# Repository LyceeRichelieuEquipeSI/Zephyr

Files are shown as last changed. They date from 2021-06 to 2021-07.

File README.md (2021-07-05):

# Zephyr
Projet de capteur de CO2 qui a été primé aux Olympiades de Sciences de l'Ingénieur 2021



Voici l'implantation des différents composants :

Implantation Arduino projet Zéphyr

Le capteur choisi au final est le CO2 Grove de chez GOtronic : https://www.gotronic.fr/art-capteur-de-co2-grove-101020067-23839.htm

Les pièces sont disponibles au format STL!

Il faut imprimer les 4 articulations.

Si vous voulez en savoir plus, voici la présentation faite lors de la finale des Olympiades : 
https://youtu.be/IQtPWZz7KpU

Celle-ci est aussi disponible en pdf dans les documents associés.

Voici également une vidéo du projet réel : 
https://www.youtube.com/watch?v=lbtuWfUY2Ug

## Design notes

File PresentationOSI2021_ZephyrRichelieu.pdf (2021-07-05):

# Projet Zéphyr

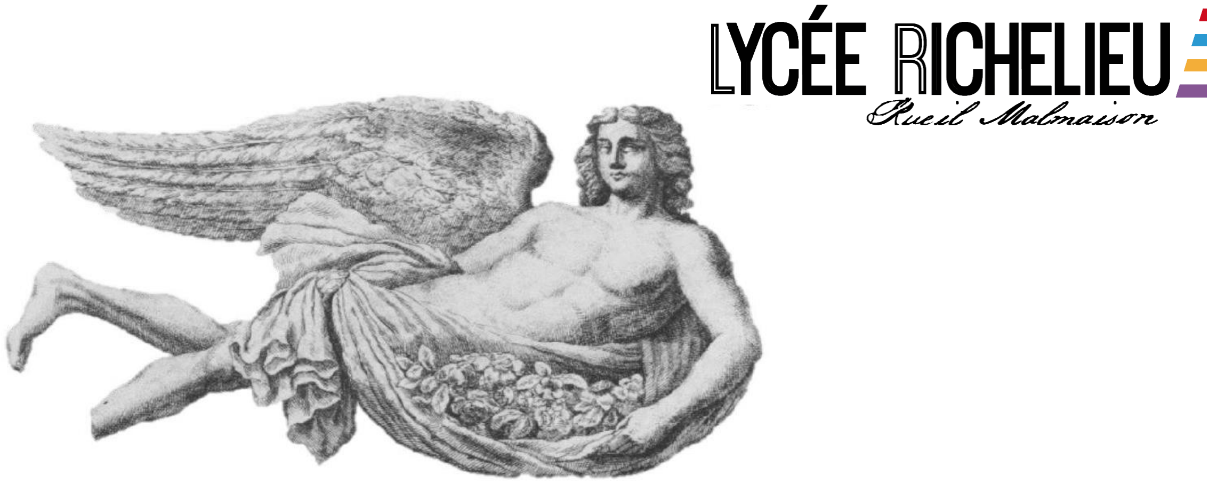
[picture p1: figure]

Le dieu grec Zéphyr,
personification du vent de l‘Ouest ou du Nord-Ouest.

Elèves de Première Spécialité Sciences de l’ingénieur

# Contexte sanitaire et social

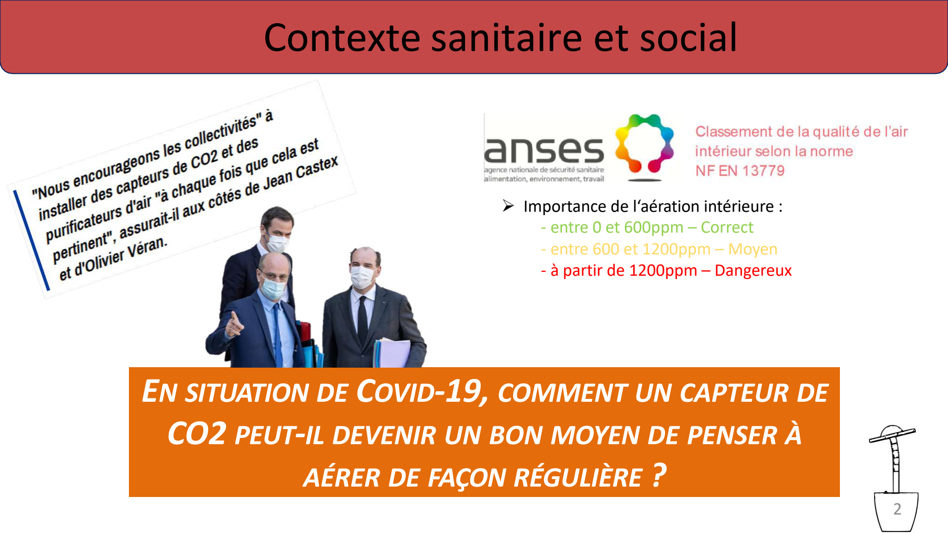
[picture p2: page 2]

## EN SITUATION DE COVID-19, COMMENT UN CAPTEUR DE CO2 PEUT-IL DEVENIR UN BON MOYEN DE PENSER À AÉRER DE FAÇON RÉGULIÈRE ?

Ø Importance de l‘aération intérieure :
- entre 0 et 600ppm – Correct
- entre 600 et 1200ppm – Moyen
- à partir de 1200ppm – Dangereux

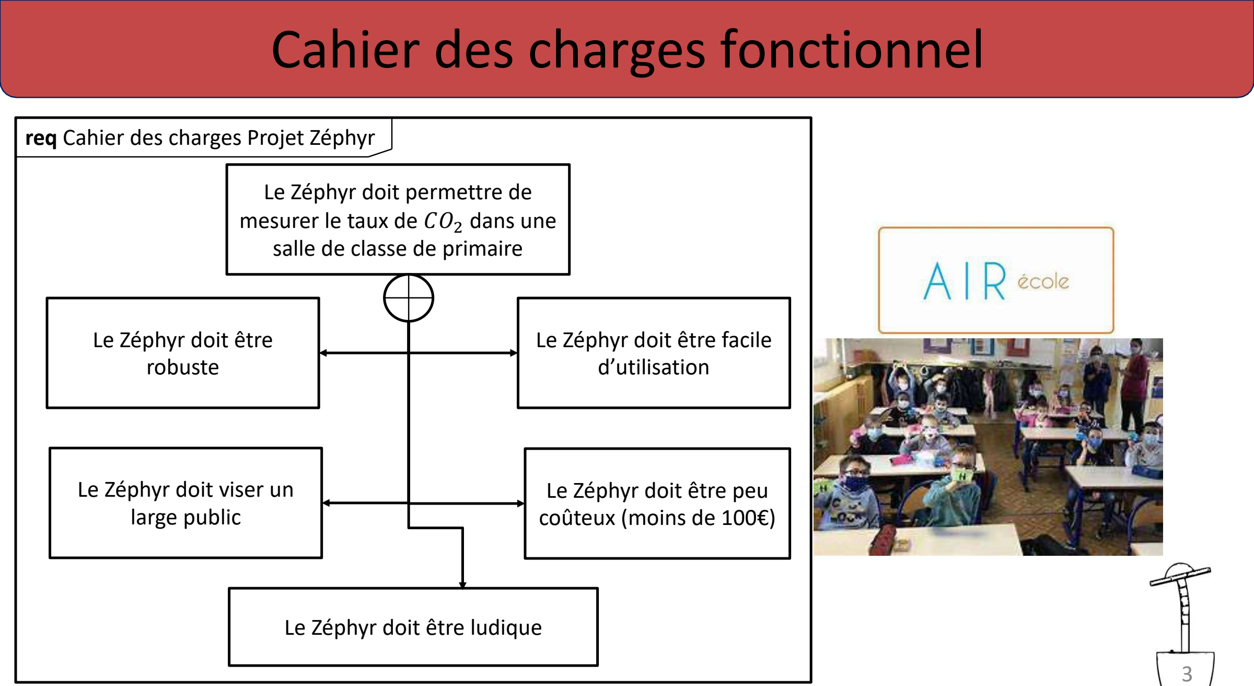
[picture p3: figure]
req Cahier des charges Projet Zéphyr; Cahier des charges fonctionnel; Le Zéphyr doit permettre de mesurer le taux de !"# dans une salle de classe de primaire; Le Zéphyr doit être facile d’utilisation; Le Zéphyr doit être peu coûteux (moins de 100€); Le Zéphyr doit être robuste; Le Zéphyr doit viser un large public; Le Zéphyr doit être ludique

# État de l’art

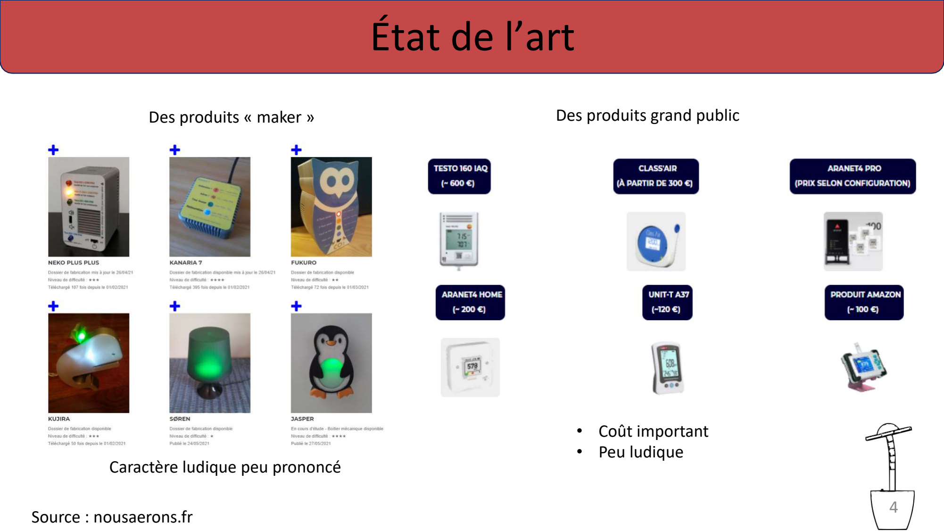
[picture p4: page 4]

Des produits grand public

- Coût important
- Peu ludique

Des produits « maker »

Caractère ludique peu prononcé

Source : nousaerons.fr | 4

# Notre projet Zéphyr

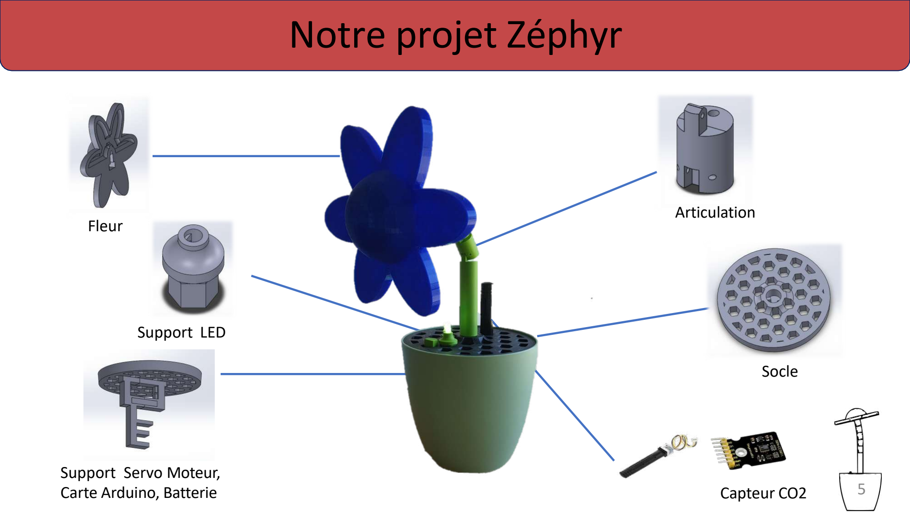
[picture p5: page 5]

Fleur

Articulation

Support LED

Capteur CO2

Support Servo Moteur,
Carte Arduino, Batterie

Socle

## Comment choisir un détecteur de CO2 ?

Un critère déterminant, la technologie du capteur.

- Capteur électrochimique trop délicat à calibrer.

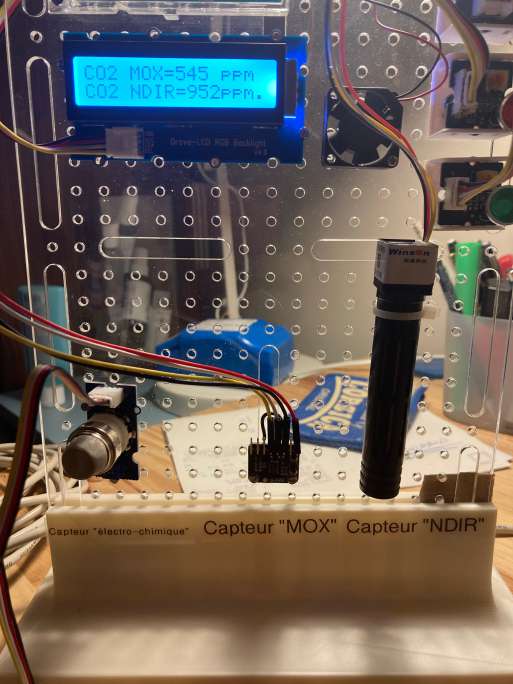
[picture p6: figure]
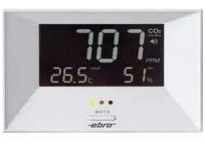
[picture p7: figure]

Banc d’essai

- Capteur NDIR certifié (a été comparé avec un capteur CO2 certifié étalonné)

Ø Les essais ont été réalisés avec deux capteurs : MOX et NDIR

# Fonction Acquérir

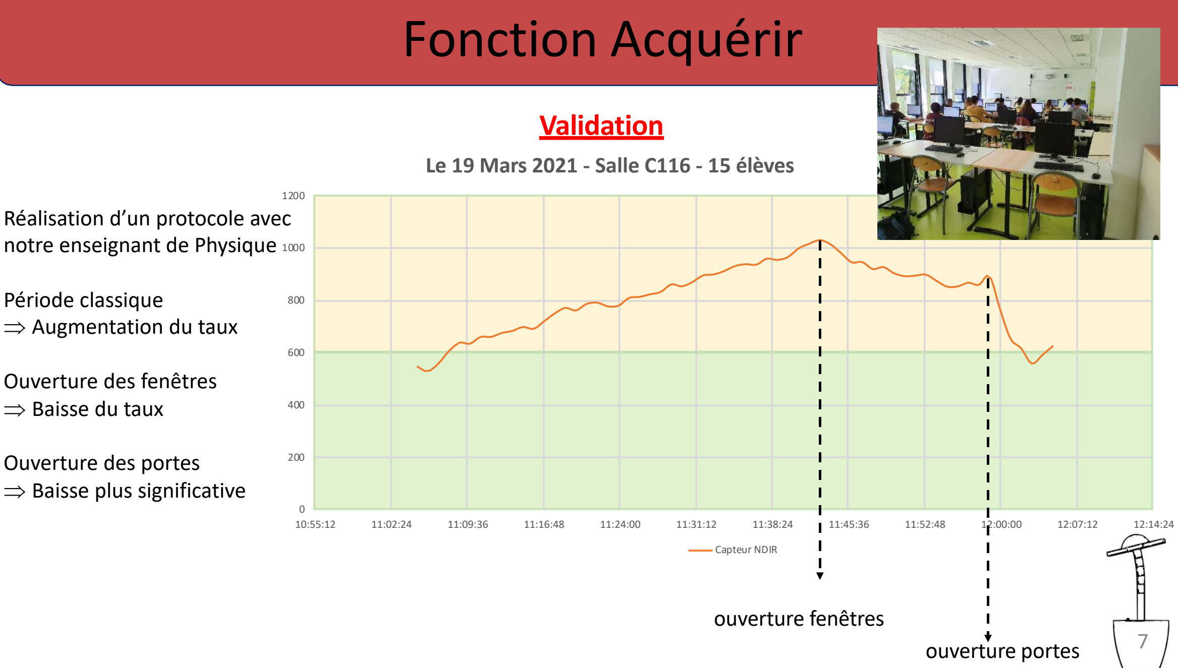
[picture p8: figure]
Fonction Acquérir; Validation; Capteur NDIR; ouverture fenêtres; ouverture portes; Réalisation d’un protocole avec notre enseignant de Physique; Période classique Þ Augmentation du taux; Ouverture des fenêtres Þ Baisse du taux; Ouverture des portes Þ Baisse plus significative

Le 19 Mars 2021 - Salle C116 - 15 élèves

# Fonction Acquérir

## Résultats des essais

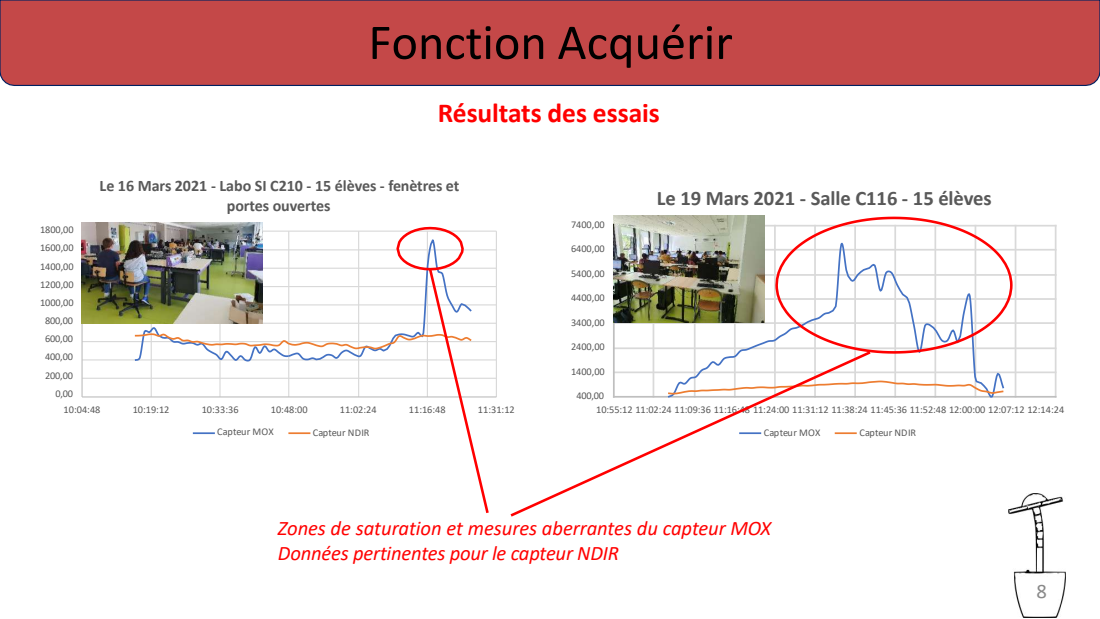
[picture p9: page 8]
portes ouvertes; Capteur MOX; Capteur NDIR

Le 16 Mars 2021 - Labo SI C210 - 15 élèves - fenètres et

Le 19 Mars 2021 - Salle C116 - 15 élèves

Zones de saturation et mesures aberrantes du capteur MOX
Données pertinentes pour le capteur NDIR

## Conclusion

## Les capteurs MOX sont à éviter !

Ø Un capteur MOX ne mesure pas directement le taux de CO2 (mais un « eCO2 », une estimation du CO2)

Ø Très sensible aux composés volatiles « parasites », comme les parfums

## Les capteurs NDIR (Non-Dispersive Infra Red) sont requis pour une

mesure exacte et fiable. De plus, ils sont très robustes.

# Fonction Acquérir

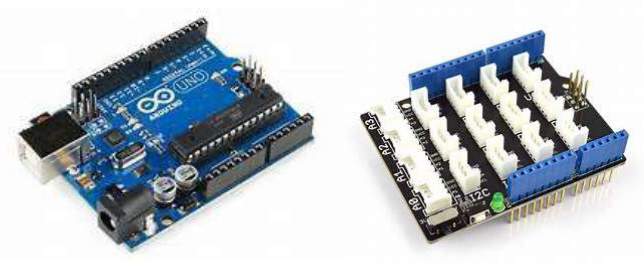
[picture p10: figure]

## - Carte Arduino UNO (microcontrôleur ATMega328 + Shield Grove)

## - Code Arduino, découpé en fonctions

# Fonction Traiter

## - Communication lumineuse

# Fonction Communiquer

## - Communication via l‘orientation

Vert – 0 à 600ppm – Correct

Jaune – 600 à 1200ppm – Moyen

Rouge – Plus de 1200ppm – Dangereux

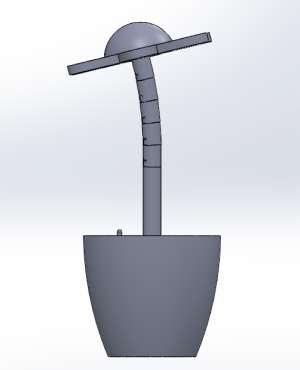
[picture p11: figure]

Plus de 1200ppm En dessous de 600 ppm

# Fonction Communiquer

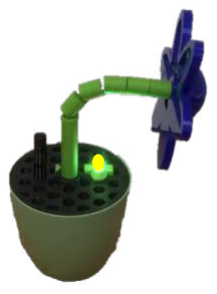
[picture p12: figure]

https://www.youtube.com/watch?v=lbtuWfUY2Ug | 12

## Taux de CO2 entre 0-600 ppm

## Taux de CO2 entre 600-1200 ppm

## Taux de CO2 de plus de 1200 ppm

## Parfait !

## Ouvrir une ou plusieurs fenêtres

## Créer un courant d‘air

## - Batterie LiPO 7.4 V – 1000 mAh - Disponible dans notre laboratoire - Modèle classique d’aéromodélisme

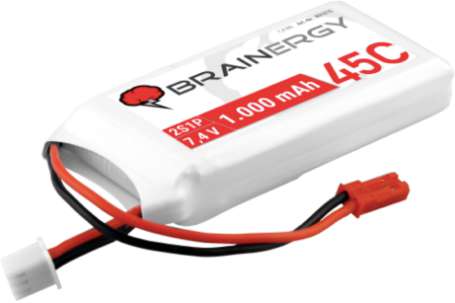
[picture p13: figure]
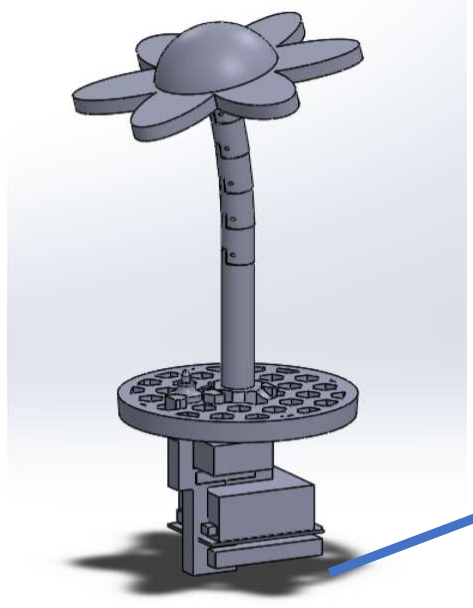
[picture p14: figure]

## Facile d‘accès

Est-ce que cette batterie tient une journée d’école ?

# Fonction Alimenter

# Fonction Alimenter

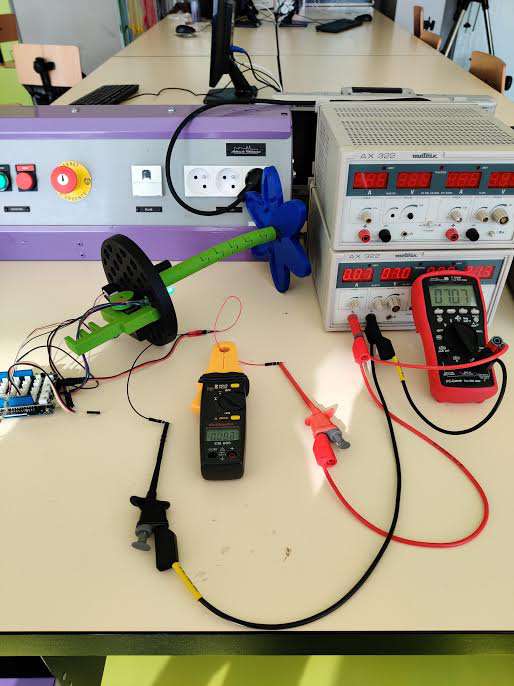
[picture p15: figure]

Mesures :

Ø Courant absorbé par la carte :

- moteur non alimenté : !" = 80 &'
- moteur alimenté : !( = 170 &'

Ø Tension mini de fonctionnement de la carte :

- +,-. = 5,2 2

### 2 hypothèses :

- Alimenté 2 fois en 1h selon le graphique pendant 2 secondes
- Le couple du moteur suffit pour le maintient de la fleur

Calculs :

Ø Courant moyen absorbé par la carte sur 1h :

- !"#$ = &
' ∑ !.*+
- !"#$ = &,- ∗/ ∗/ 0 1- ∗ 23--4/ ∗/ 23--
- !"#$ = 80,1 9:

Ø Autonomie:

* = ;
<=>?
t = 1000/80,1
t = 12,48 h = 12h 28 min

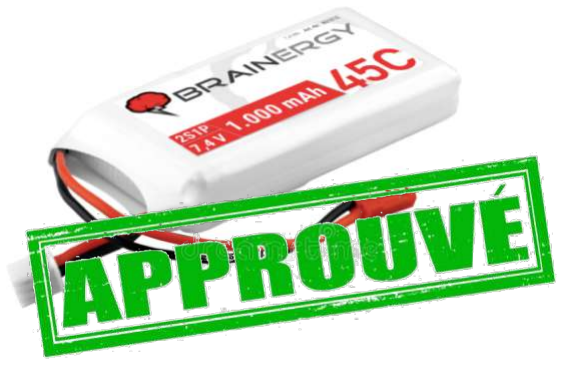
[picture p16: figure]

Beaucoup d’approximation, souhait de vérifier par modèle multiphysique

# Fonction Alimenter

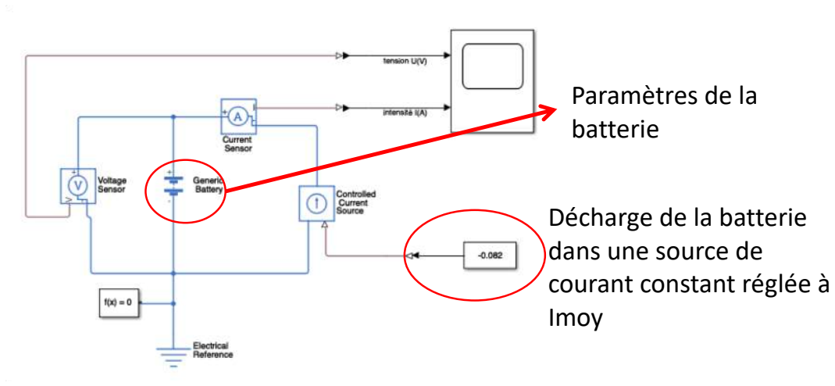
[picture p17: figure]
Décharge de la batterie dans une source de courant constant réglée à Imoy; Paramètres de la batterie
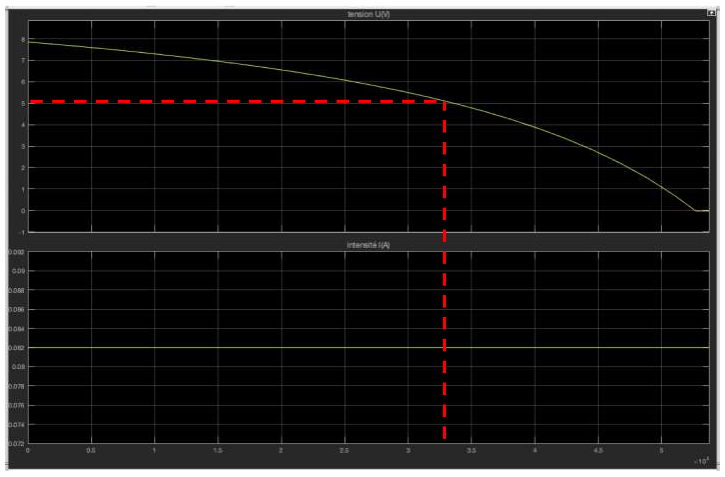
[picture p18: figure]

### Résultats de la simulation :

Pour !"#$ = 5.2 ) on a, t = 3.3 x 10⁴ s

Soit une autonomie de : 3.3 x 10⁴ /3600 = 9,17h = 9h 10 min

# Fonction Alimenter

## - Servomoteur Grove

# Fonction Convertir

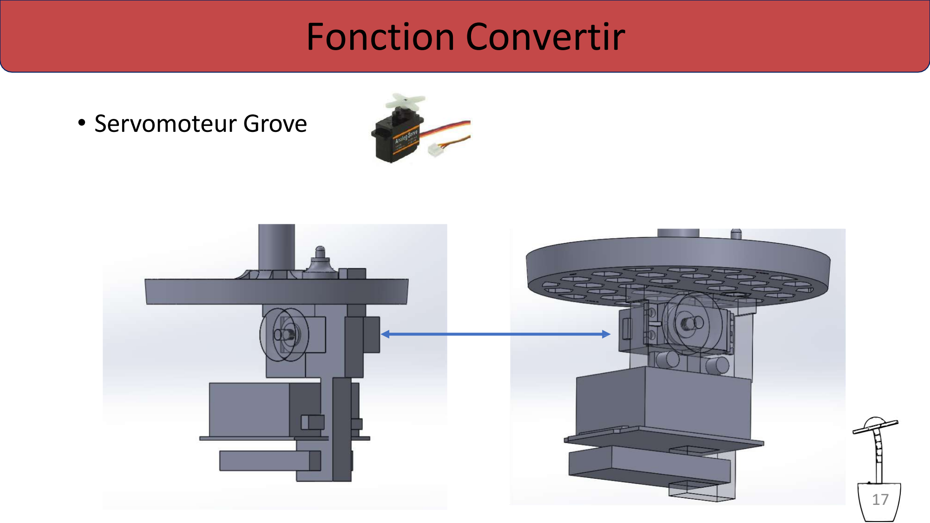
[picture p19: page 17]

## - Système poulie et câble :

# Fonction Transmettre

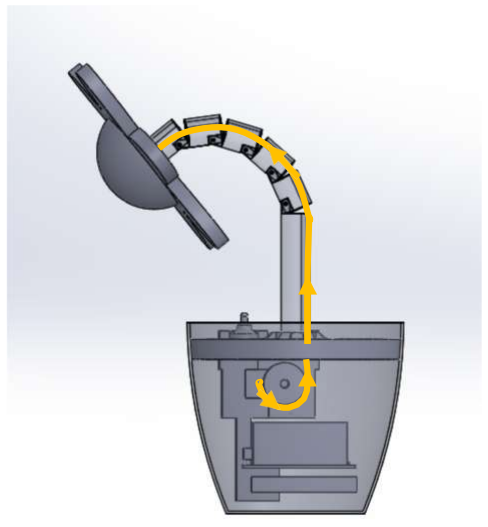
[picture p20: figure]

Lors de la rotation (sens1) du moteur, la poulie "déroule" du câble :
☞ la fleur s‘incline

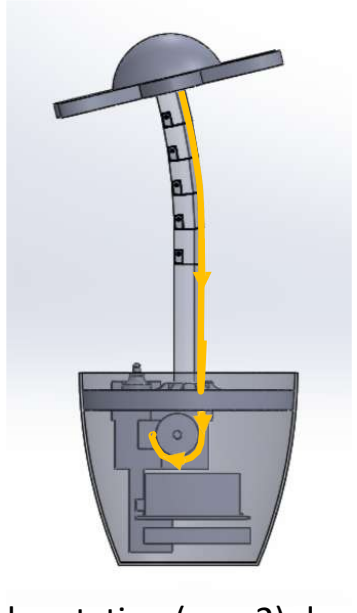
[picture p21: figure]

Lors de la rotation (sens2) du moteur, la poulie "enroule" du câble :
☞ la fleur se redresse

# Coût

Inducteurs de coût | Coût
Composants électroniques | 1+2+10+80 = 93 €
Matière première plastique | 14*0.6 = 8.4 €
Frais d’études
Amortir l’imprimante 3D (sur 1000 produits) | 600/1000 = 0.6 €
Amortir les licences Solidworks et Mathworks (sur 1000 produits) | (8000+2000)/1000 = 10 €
TOTAL | 112 €

# Bilan du projet

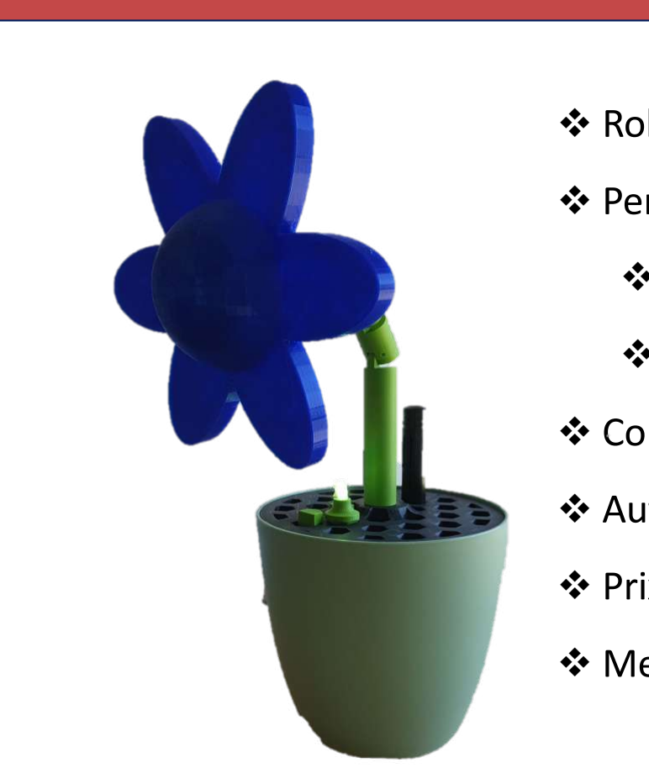
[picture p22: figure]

## v Robuste v Personnalisable : v Pot interchangeable v Nombre de niveaux intermédiaires choisissable v Communication par mouvement v Autonomie de plus de 9h v Prix d’environ 100 € v Mesure fiable du taux de CO2

# Bilan personnel

## v Mettre en place un protocole expérimental afin de valider les performances d‘un capteur et d’une batterie

## v Apprendre à structurer son code

## v Apprendre à trouver un compromis entre esthétique et solutions techniques

## v Apprendre à travailler en groupe

# Notre projet dans son contexte

## vUtilisation dans les locaux du lycée

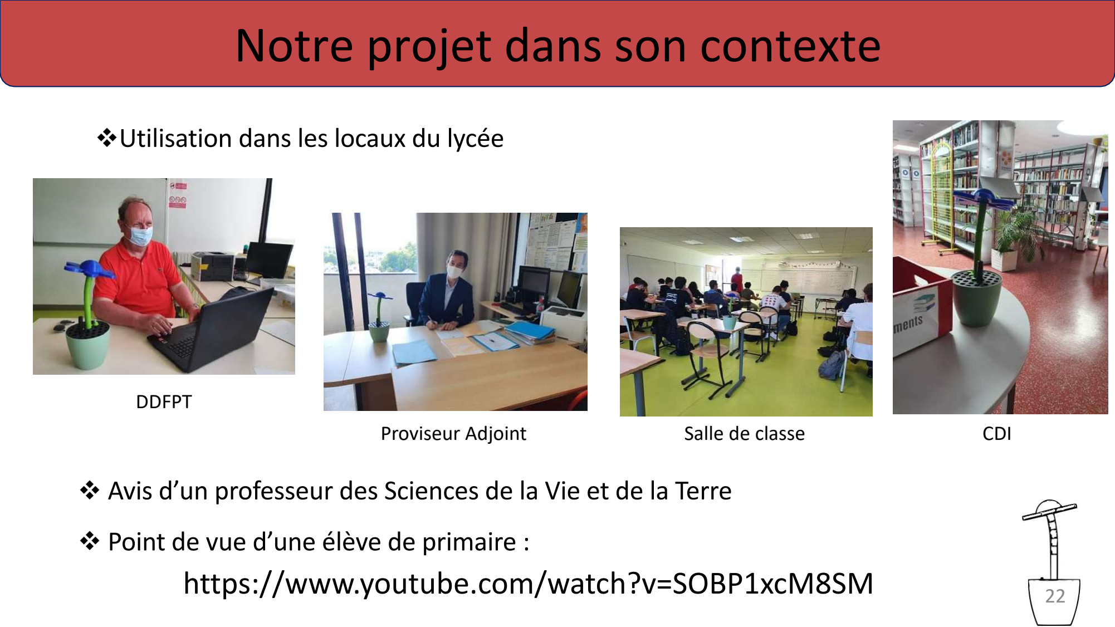
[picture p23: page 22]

## v Avis d’un professeur des Sciences de la Vie et de la Terre v Point de vue d’une élève de primaire :

## https://www.youtube.com/watch?v=SOBP1xcM8SM

DDFPT
Proviseur Adjoint | Salle de classe | CDI

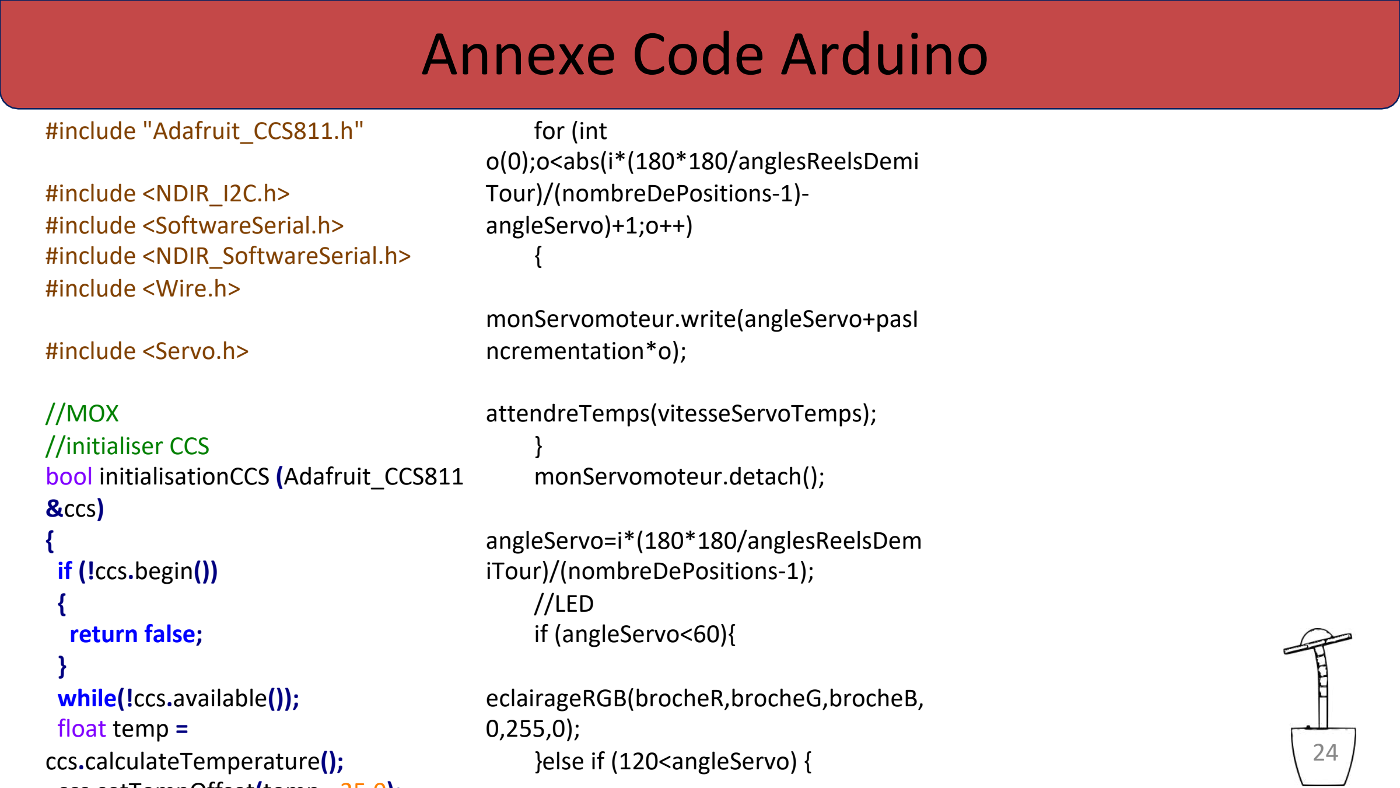
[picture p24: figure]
Annexe Code Arduino; #include "Adafruit_CCS811.h"; #include <NDIR_I2C.h> #include <SoftwareSerial.h> #include <NDIR_SoftwareSerial.h> #include <Wire.h>; #include <Servo.h>; //MOX //initialiser CCS bool initialisationCCS (Adafruit_CCS811 &ccs) {; if (!ccs.begin()) {; return false;; } while(!ccs.available()); float temp = ccs.calculateTemperature();; for (int o(0);o<abs(i*(180*180/anglesReelsDemi Tour)/(nombreDePositions-1)- angleServo)+1;o++) {; monServomoteur.write(angleServo+pasI ncrementation*o);; attendreTemps(vitesseServoTemps); } monServomoteur.detach();; angleServo=i*(180*180/anglesReelsDem iTour)/(nombreDePositions-1); //LED if (angleServo<60){; eclairageRGB(brocheR,brocheG,brocheB, 0,255,0);; }else if (120<angleServo) {

ccs.setTempOffset(temp - 25.0);

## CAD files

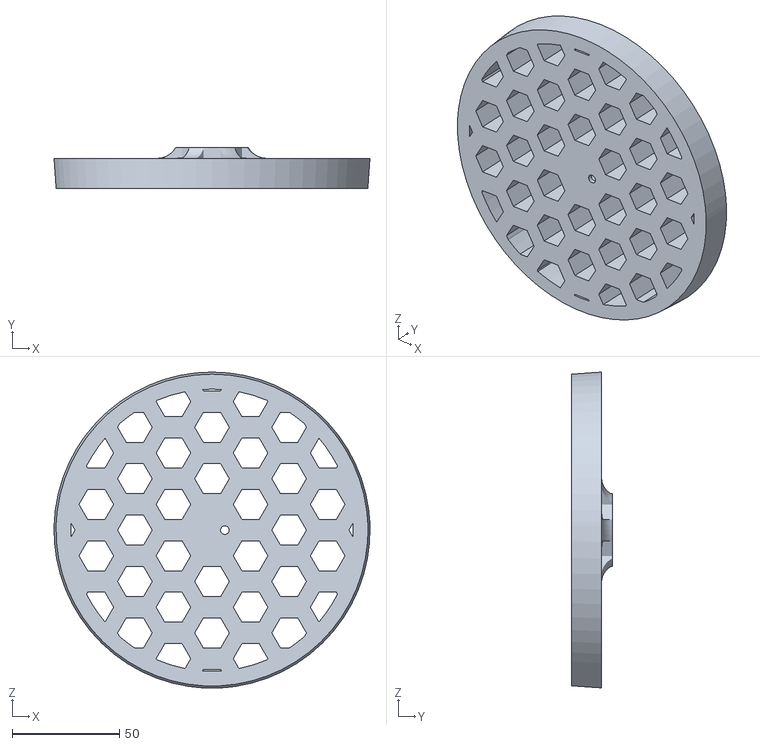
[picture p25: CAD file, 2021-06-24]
Fichiers STL/Fleur matlab - socle-1.STL
147.5 x 19.0 x 147.5

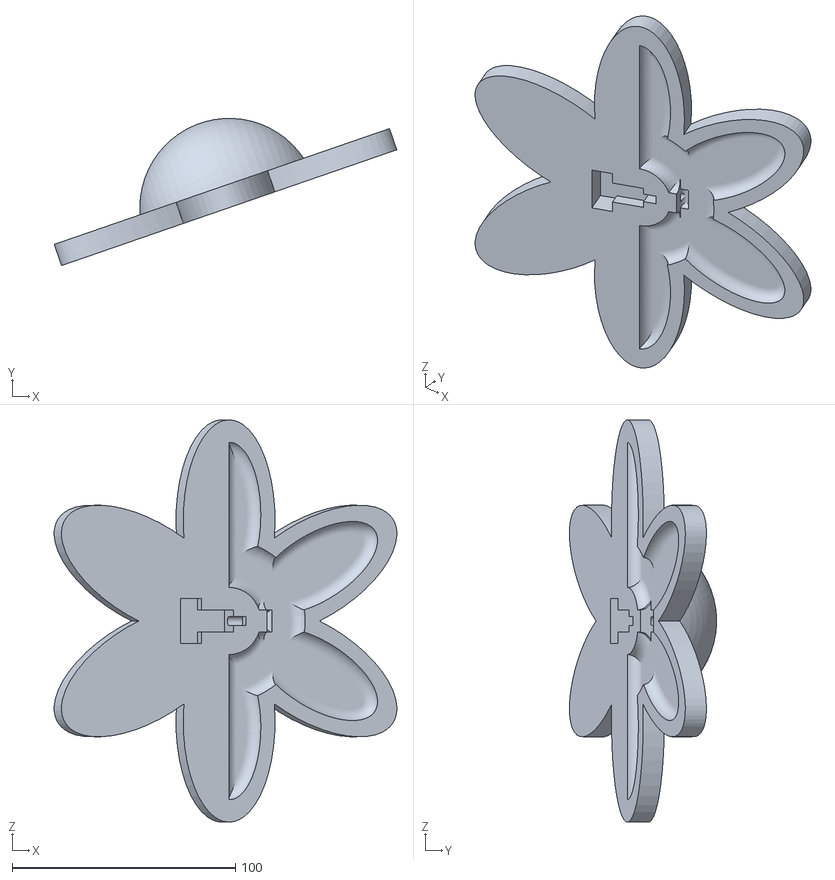
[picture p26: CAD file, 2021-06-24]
Fichiers STL/Fleur matlab - fleur-1.STL
153.3 x 65.8 x 179.9

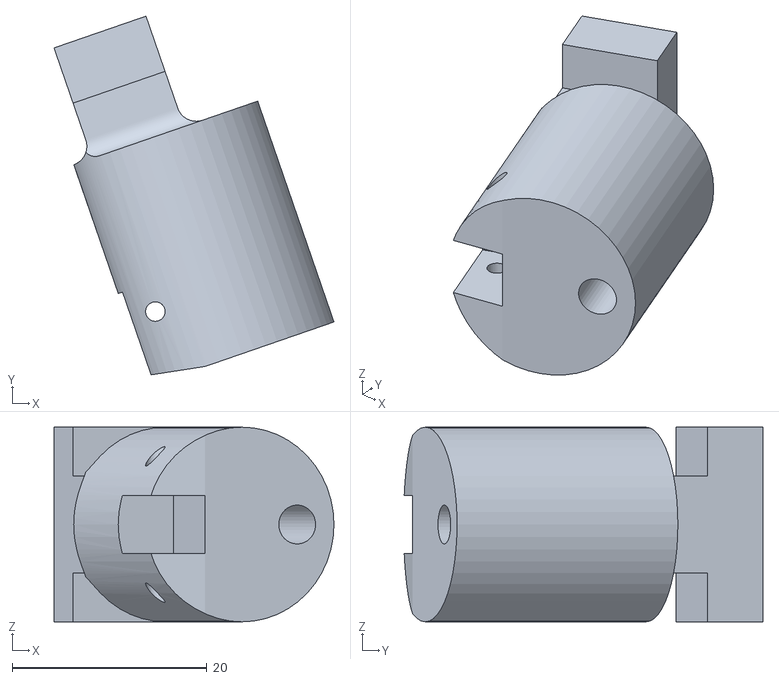
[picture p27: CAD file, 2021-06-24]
Fichiers STL/Fleur matlab - pieceArticulationFleur-1.STL
28.8 x 36.8 x 20.0

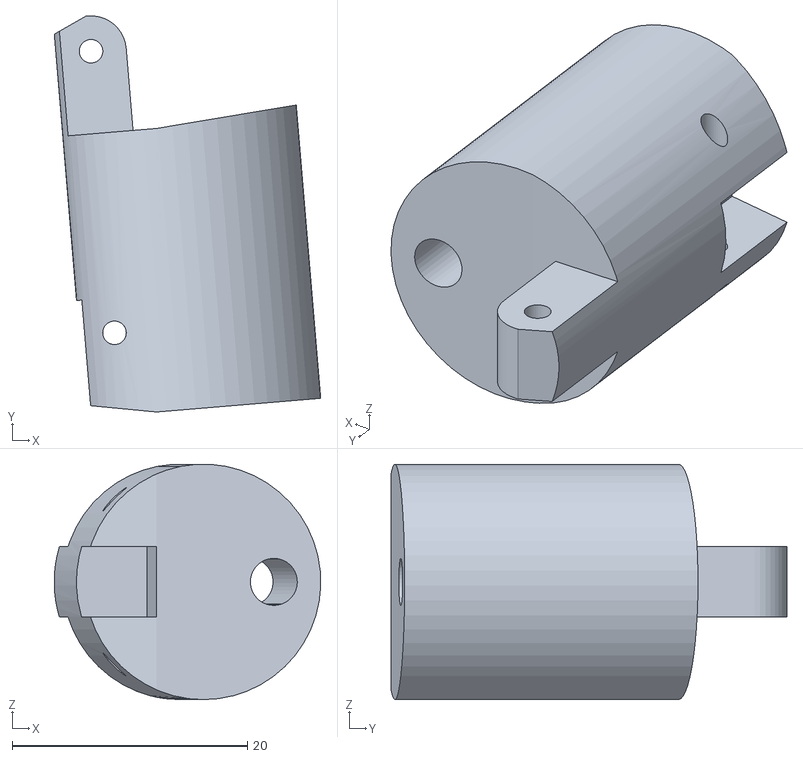
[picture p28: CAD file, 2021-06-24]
Fichiers STL/Fleur matlab - pieceArticulation-2.STL
22.6 x 33.6 x 20.0

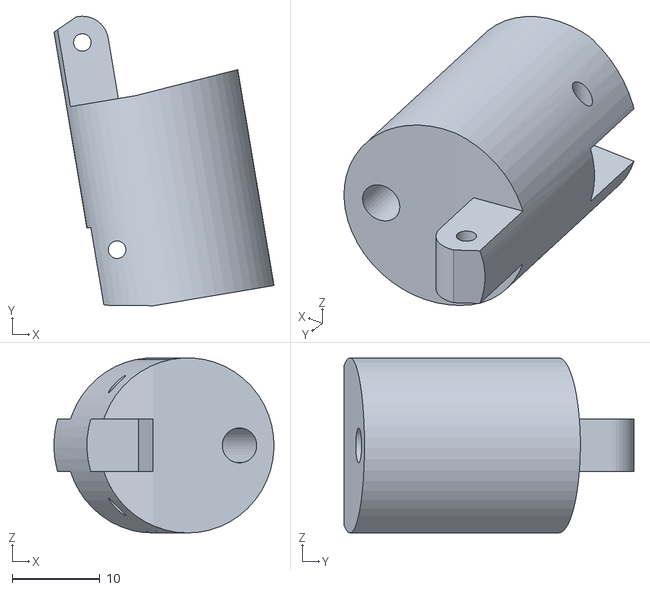
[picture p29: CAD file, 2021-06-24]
Fichiers STL/Fleur matlab - pieceArticulation-3.STL
25.1 x 33.1 x 20.0

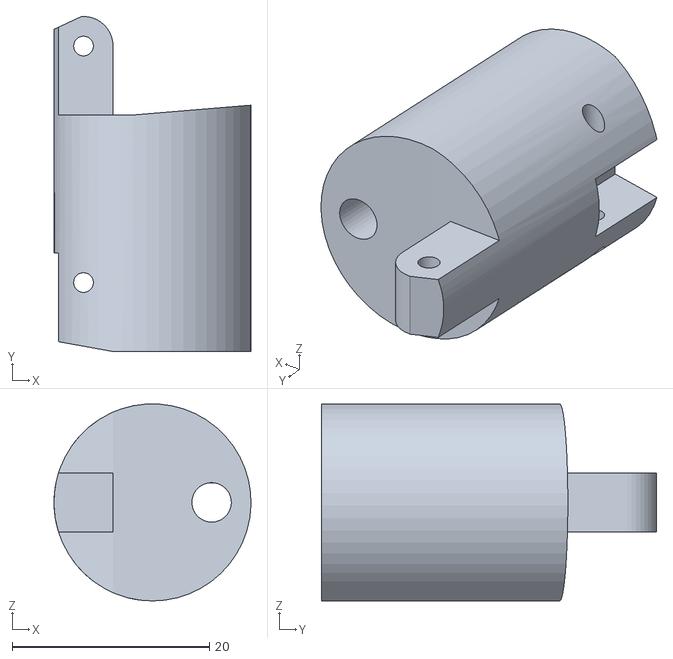
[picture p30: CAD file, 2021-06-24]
Fichiers STL/Fleur matlab - pieceArticulation-1.STL
20.0 x 34.0 x 20.0

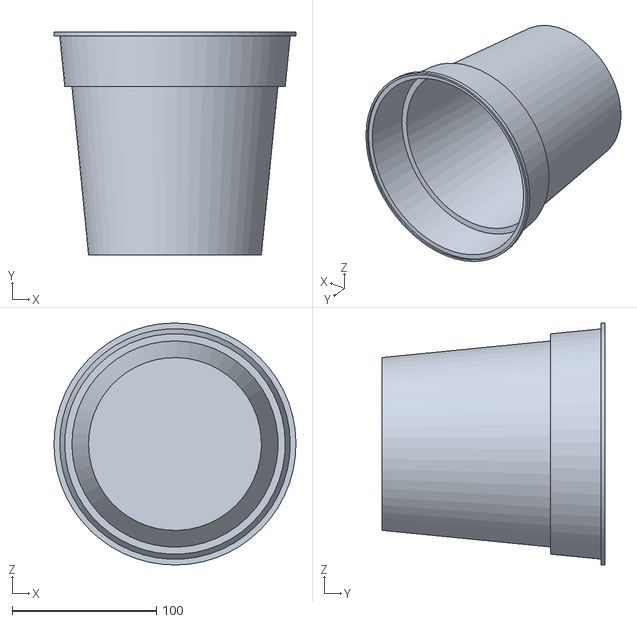
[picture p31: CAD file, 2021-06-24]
Fichiers STL/Fleur matlab - Pot-1.STL
168.0 x 155.0 x 168.0

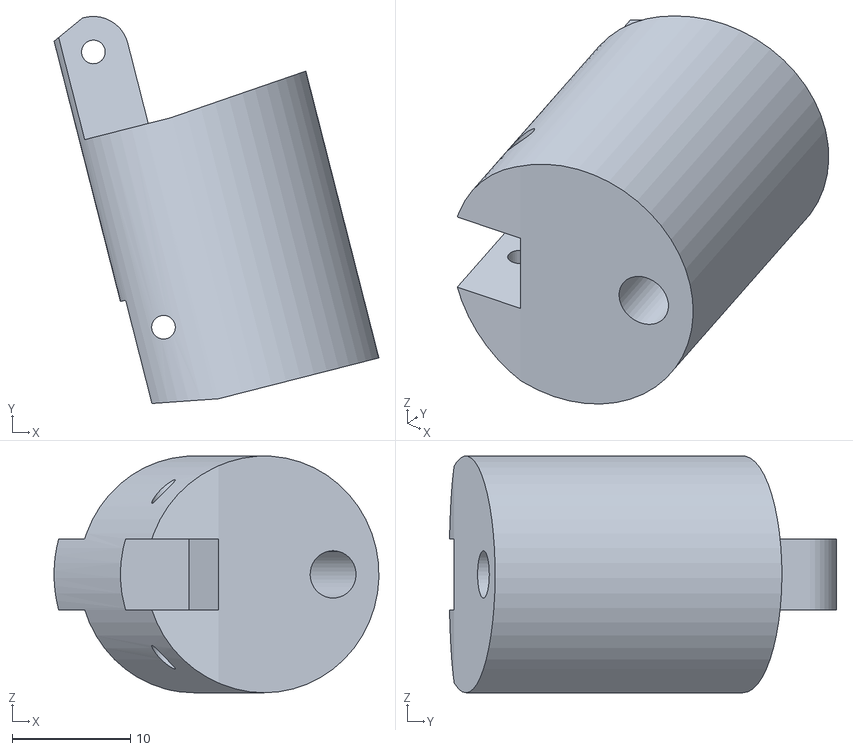
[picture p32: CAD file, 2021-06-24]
Fichiers STL/Fleur matlab - pieceArticulation-4.STL
27.4 x 32.7 x 20.0

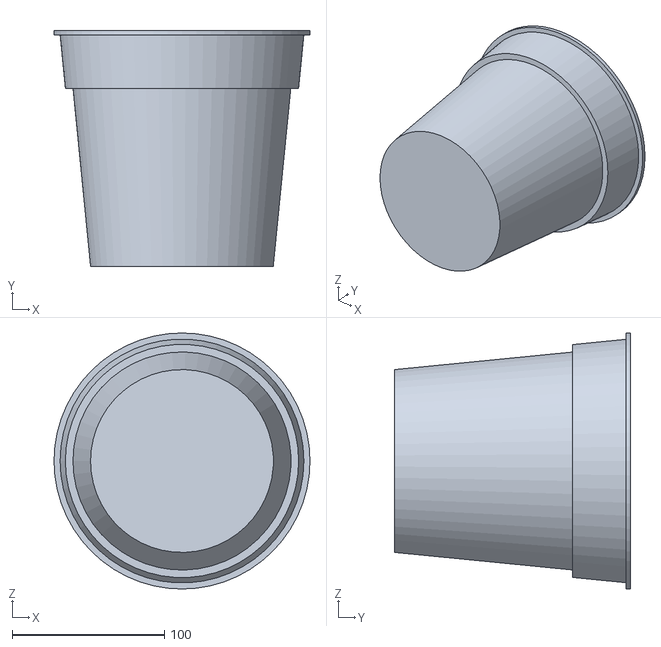
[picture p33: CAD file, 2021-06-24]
Fichiers STL/Pot.STL
168.0 x 155.0 x 168.0

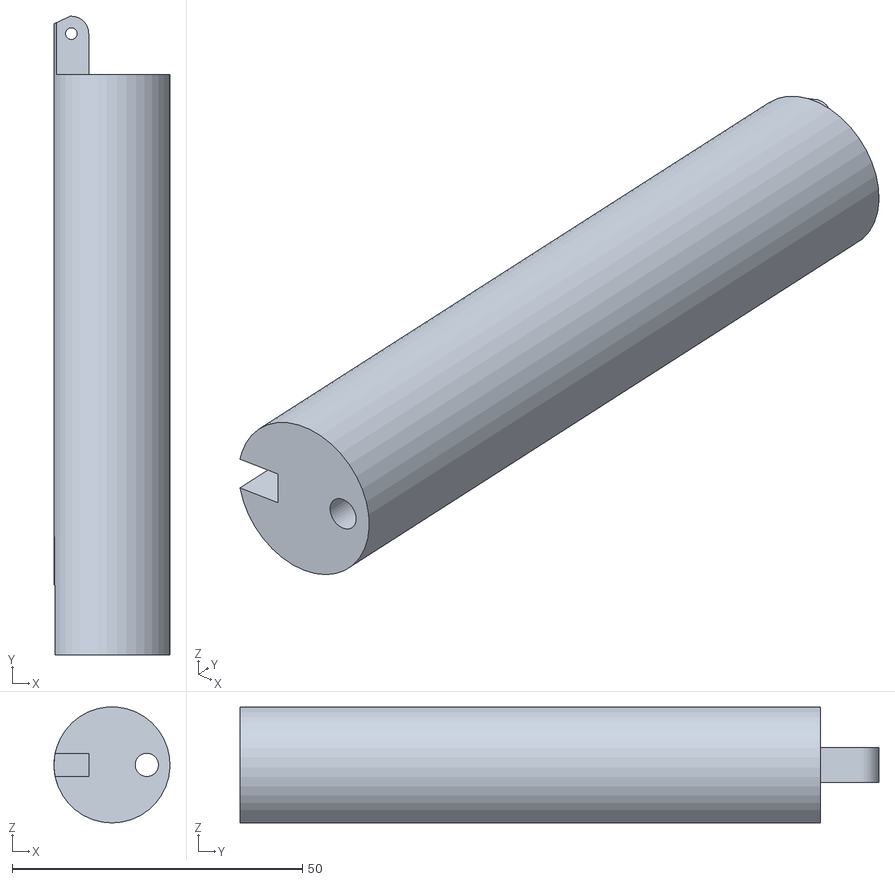
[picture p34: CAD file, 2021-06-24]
Fichiers STL/Fleur matlab - pieceTige-1.STL
20.0 x 110.0 x 20.0

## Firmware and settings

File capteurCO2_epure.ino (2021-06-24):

#include "Adafruit_CCS811.h"

#include <NDIR_I2C.h>
#include <SoftwareSerial.h>
#include <NDIR_SoftwareSerial.h>
#include <Wire.h>

#include <Servo.h>

//MOX
//initialiser CCS
bool initialisationCCS (Adafruit_CCS811 &ccs)
{
  if (!ccs.begin())
  {
    return false;
  }
  while(!ccs.available());
  float temp = ccs.calculateTemperature();
  ccs.setTempOffset(temp - 25.0);
  return true;
}

//recevoir valeur TVOC
float valeurTVOC (Adafruit_CCS811 &ccs)
{
  if(ccs.available())
  {
    if(!ccs.readData())
    {
      return ccs.geteCO2();
    }
    else
    {
      return -1.0;
    }
  }
  else
  {
    return -2.0;
  }
}

//NDIR
//initialiser
bool initialisationNDIR (NDIR_SoftwareSerial &ndir)
{
  if (!ndir.begin()) 
  {
      return false;
  }
  return true;
}

//recevoir valeur TVOC
float valeurTVOC (NDIR_SoftwareSerial &ndir)
{
  if (ndir.measure()) 
  {
    return ndir.ppm;
  }
  else
  {
    return -1.0;
  }
}

//inititaliser RGB
void initialisationRGB (int const& brocheR, int const& brocheG, int const& brocheB)
{
  pinMode(brocheR, OUTPUT);
  pinMode(brocheG, OUTPUT);
  pinMode(brocheB, OUTPUT);
  analogWrite(brocheR, 0);
  analogWrite(brocheG, 0);
  analogWrite(brocheB, 0);
}

//eclairer RGB
void eclairageRGB(int const& brocheR, int const& brocheG, int const& brocheB, int const& r, int const& g, int const& b)
{
  analogWrite(brocheR, r);
  analogWrite(brocheG, g);
  analogWrite(brocheB, b);
}

//attendre temps
void attendreTemps(int const& mlls)
{
  unsigned long tempsDebut = millis();
  while(millis()-tempsDebut < mlls);
}


//Servomoteur et CCS
Servo monServomoteur;
Adafruit_CCS811 ccs;
NDIR_SoftwareSerial ndir(2,3);

//VARIABLES GLOBALES
//Utlisateur
const float nombreDePositions=3.0;
const float anglesReelsDemiTour=220;
const float vitesseServoTemps=20;
const int angleDOrigine=0;
const int brocheR=11;
const int brocheG=10;
const int brocheB=9;
const int brocheServomoteur=4;
//Programme
float TVOC;
int angleServo=angleDOrigine;
int pasIncrementation;

void setup() {
  Serial.begin(9600);
  Serial.println("NDIR test ");

  while(!initialisationNDIR(ndir));
  initialisationRGB(brocheR,brocheG,brocheB);

  monServomoteur.attach(brocheServomoteur);
  while(!monServomoteur.attached());
  monServomoteur.write(angleDOrigine);
  attendreTemps(1000);
  monServomoteur.detach();
  eclairageRGB(brocheR,brocheG,brocheB,0,255,0);
  Serial.println("Initialisation réussie...");
}

void loop() {
  attendreTemps(1000);
  TVOC = valeurTVOC(ndir);
  if (0<TVOC){
    Serial.print("tvoc : ");
    Serial.print(TVOC);
    Serial.print("     degres var : ");
    Serial.print(angleServo);
    Serial.print("     degres reels: ");
    Serial.println(monServomoteur.read());
    for (int i(0);i<nombreDePositions;i++)
    {
      if (((i*(1800/nombreDePositions)<= TVOC)&(TVOC <= (i+1)*(1800/nombreDePositions)))|(i==nombreDePositions-1))
      {
        if ((i*(180*180/anglesReelsDemiTour)/(nombreDePositions-1)-angleServo)>0)
        {
          pasIncrementation=1;
        }
        else if((i*(180*180/anglesReelsDemiTour)/(nombreDePositions-1)-angleServo)==0)
        {
          break;
        }
          else
        {
          pasIncrementation=-1;
        }
        monServomoteur.attach(brocheServomoteur);
        while(!monServomoteur.attached());
        for (int o(0);o<abs(i*(180*180/anglesReelsDemiTour)/(nombreDePositions-1)-angleServo)+1;o++)
        {
          monServomoteur.write(angleServo+pasIncrementation*o);
          attendreTemps(vitesseServoTemps);
        }
        monServomoteur.detach();
        angleServo=i*(180*180/anglesReelsDemiTour)/(nombreDePositions-1);
        //LED
        if (angleServo<60){
          eclairageRGB(brocheR,brocheG,brocheB,0,255,0);
        }else if (120<angleServo) {
          eclairageRGB(brocheR,brocheG,brocheB,255,0,0);
        }else{
          eclairageRGB(brocheR,brocheG,brocheB,255,255,0);
        }
        break;
      }
    }
  }
}
